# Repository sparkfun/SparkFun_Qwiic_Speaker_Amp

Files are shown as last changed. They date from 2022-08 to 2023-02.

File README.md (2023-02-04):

SparkFun Qwiic Speaker Amp
========================================

SparkFun Qwiic Speaker Amp - TPA2016D2 (https://www.sparkfun.com/products/20690)

[*SparkFun Qwiic Speaker Amp (DEV-20690)*](https://www.sparkfun.com/products/20690)

The SparkFun Qwiic Speaker Amp includes the Texas Instruments TPA2016D2 stereo, filter-free class-D audio power amplifier. What distinguishes this audio amplifier from others is that it features volume control (i.e. gain), Dynamic Range Compression (DRC), Automatic Gain Control (AGC), enable/disable amplifier, and its ability to be configured through software via I<sup>2</sup>C. Its efficient class-D operation also means low heat and long battery life when driving 4&ohm; speakers at up to 2.8W in stereo, and 8&ohm; speakers at up to 1.7W in stereo. This is quite a bit more power than the [mono amplifier (TPA2005D1) ](https://www.sparkfun.com/products/11044) or [Noisy Cricket stereo amplifier (LM4853)](https://www.sparkfun.com/products/14475). It won't shake a stadium but it will provide plenty of volume for your audio projects.

The DRC and AGC is unique compared to other audio amplifiers. This is a powerful feature that allows you to "even out" the loud and quiet sections from your audio input. It also allows you to maximize the volume of your speakers. By fine-tuning the settings, you can get the most volume to prevent distortion of the audio signal. Using the DRC, AGC, and/or the limiter alone allows you to protect your speakers from getting damaged by extremely loud playback. We've written an extensive Arduino Library that allows you to easily control all of the amplifier's features from simple gain control to advanced AGC. Note that you will need to send the configuration to the TPA2016D2 upon every power cycle. 

The board has been designed to be user friendly! Screw terminals are provided for the audio input, power, shutdown, and speaker output. A 3.5mm TRS connector is included as an alternative to easily insert an audio cable. Utilizing our handy Qwiic system, no soldering is required to connect it to the rest of your system when configuring the amplifier's settings. A power LED (PWR) is included on the board to indicate when power is applied to the amplifier through VIN. It can be disabled by cutting the LED jumper on the bottom side. For users that do not want to power the board with a separate power supply, you can close the JP1 jumper and use the same power supply as the microcontroller via the Qwiic connector's 3.3V pin.

This board is great for projects that require you to amplify an audio signal for small, differential speakers. This breakout is also great when pairing it with your smartphone, computer, portable digital player, or any audio boards (such as the MP3 Trigger, Tsunami Super WAV Trigger, MP3 Player Shield, or Music Instrument Shield to name a few)! Add the Qwiic Speaker Amp in your next portable projects such as sound effects for your spooky Halloween pumpkin, wearable costumes, props, talking greeting cards, or USB speakers.

Repository Contents
-------------------

* **/Documentation** - Datasheets, additional product information
* **/Hardware** - Eagle design files (.brd, .sch)
  * **/Production** - Production panel files (.brd)

Documentation
--------------

* **[Installing an Arduino Library Guide](https://learn.sparkfun.com/tutorials/installing-an-arduino-library)** - Basic information on how to install an Arduino library.
* **[Library](https://github.com/sparkfun/SparkFun_TPA2016D2_Arduino_Library)** - Arduino library for the Qwiic Speaker Amp.
* **[SparkFun Fritzing repo](https://github.com/sparkfun/Fritzing_Parts/blob/main/products/20690_sfe_qwiic_speaker_amplifier_tpa2016d2_stereo_audio.fzpz)** - Fritzing diagrams for SparkFun products.
* **[Hookup Guide](https://learn.sparkfun.com/tutorials/2749)** - Basic hookup guide for the Qwiic Speaker Amp.

Product Versions
----------------

* **[DEV-20690](https://www.sparkfun.com/products/20690)** - Initial release

Version History
---------------
* v1.0 - Initial release

License Information
-------------------

This product is _**open source**_! 

Please review the LICENSE.md file for license information. 

If you have any questions or concerns on licensing, please contact technical support on our [SparkFun forums](https://forum.sparkfun.com/viewforum.php?f=152).

Distributed as-is; no warranty is given.

- Your friends at SparkFun.

_<COLLABORATION CREDIT>_

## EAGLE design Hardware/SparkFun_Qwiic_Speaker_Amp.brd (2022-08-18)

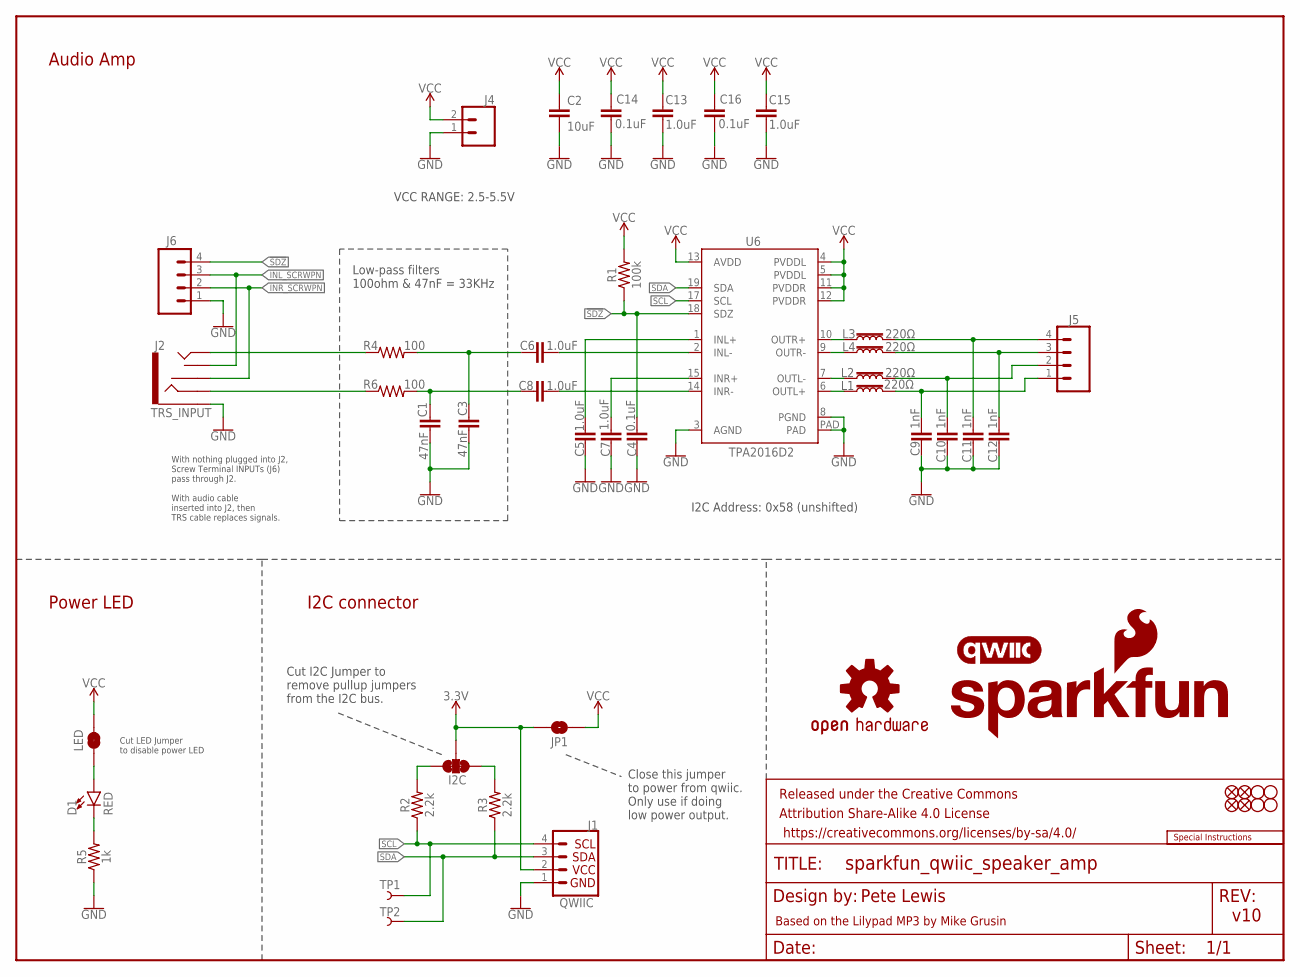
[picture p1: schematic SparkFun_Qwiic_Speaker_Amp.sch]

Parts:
C1, C3: 47nF; 0402-TIGHT
C2: 10uF; 0805
C4, C14, C16: 0.1uF; 0402-TIGHT
C5, C6, C7, C8, C13, C15: 1.0uF; 0402-TIGHT
C9, C10, C11, C12: 1nF; 0402
D1: RED; LED-0603
FD1, FD2, FD3, FD4: FIDUCIAL1X2; FIDUCIAL-1X2
FRAME2: FRAME-LETTER; CREATIVE_COMMONS
H1, H2, H3, H4: STAND-OFFTIGHT; STAND-OFF-TIGHT
I2C: JUMPER-SMT_3_2-NC_TRACE_SILK; SMT-JUMPER_3_2-NC_TRACE_SILK
J1: QWIIC; JST04_1MM_RA
J2: TRS_INPUT; AUDIO-JACK-3.5MM-SMD
J4: CONN_023.5MM; SCREWTERMINAL-3.5MM-2
J5: CONN_04SCREW; SCREWTERMINAL-3.5MM-4
J6: SCREW; SCREWTERMINAL-3.5MM-4
JP1: JP1; SMT-JUMPER_2_NO_SILK
L1, L2, L3, L4: 220Ω; 0805
LED: JUMPER-SMT_2_NC_TRACE_SILK; SMT-JUMPER_2_NC_TRACE_SILK
LOGO2: SFE_LOGO_NAME_FLAME.1_INCH; SFE_LOGO_NAME_FLAME_.1
LOGO3: QWIIC_LOGO_4MM; QWIIC_4MM
LOGO4: OSHW-LOGOS; OSHW-LOGO-S
LOGO6: SPECIAL_INSTRUCTIONS-ORDERING; ORDERING_INSTRUCTIONS
R1: 100k; 0402-TIGHT
R2, R3: 2.2k; 0402-TIGHT
R4, R6: 100; 0402-TIGHT
R5: 1k; 0402-TIGHT
TP1, TP2: TEST-POINTTP_15TH_THRU; TP_15TH
U6: TPA2016D2; QFN-20-0.5MM

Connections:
3.3V: I2C.2, J1.2, JP1.1
!SDZ!: C4.1, J6.4, R1.1, U6.18 (SDZ)
GND: C1.2, C2.2, C3.2, C4.2, C5.1, C7.1, C9.2, C10.2, C11.2, C12.2, C13.2, C14.2, C15.2, C16.2, J1.1, J2.SLEEVE, J4.1, J6.1, R5.1, U6.3 (AGND), U6.8 (PGND), U6.PAD
INL: J2.TIP, R4.1
INL_SCRWPN: J2.TSH, J6.3
INR: J2.RING, R6.1
INR_SCRWPN: J2.RSH, J6.2
unnamed: L1.1, U6.6 (OUTL+)
unnamed: L2.1, U6.7 (OUTL-)
unnamed: C1.1, C8.1, R6.2
unnamed: D1.C, R5.2
unnamed: C3.1, C6.1, R4.2
unnamed: D1.A, LED.1
unnamed: I2C.3, R2.2
unnamed: I2C.1, R3.2
unnamed: L3.1, U6.10 (OUTR+)
unnamed: L4.1, U6.9 (OUTR-)
unnamed: C8.2, U6.14 (INR-)
unnamed: C5.2, U6.1 (INL+)
unnamed: C6.2, U6.2 (INL-)
unnamed: C7.2, U6.15 (INR+)
SCL: J1.4, R2.1, TP1.1, U6.17 (SCL)
SDA: J1.3, R3.1, TP2.1, U6.19 (SDA)
SPK_L_+: C9.1, J5.1, L1.2
SPK_L_-: C10.1, J5.2, L2.2
SPK_R_+: C11.1, J5.4, L3.2
SPK_R_-: C12.1, J5.3, L4.2
VCC: C2.1, C13.1, C14.1, C15.1, C16.1, J4.2, JP1.2, LED.2, R1.2, U6.4 (PVDDL), U6.5 (PVDDL), U6.11 (PVDDR), U6.12 (PVDDR), U6.13 (AVDD)

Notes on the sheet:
Pete Lewis
Audio Amp
Cut I2C Jumper to remove pullup jumpers from the I2C bus.
v10
Based on the Lilypad MP3 by Mike Grusin
Low-pass filters 100ohm & 47nF = 33KHz
With nothing plugged into J2, Screw Terminal INPUTs (J6) pass through J2. With audio cable inserted into J2, then TRS cable replaces signals.
VCC RANGE: 2.5-5.5V
Cut LED Jumper to disable power LED
Power LED
I2C connector
Close this jumper to power from qwiic. Only use if doing low power output.
I2C Address: 0x58 (unshifted)

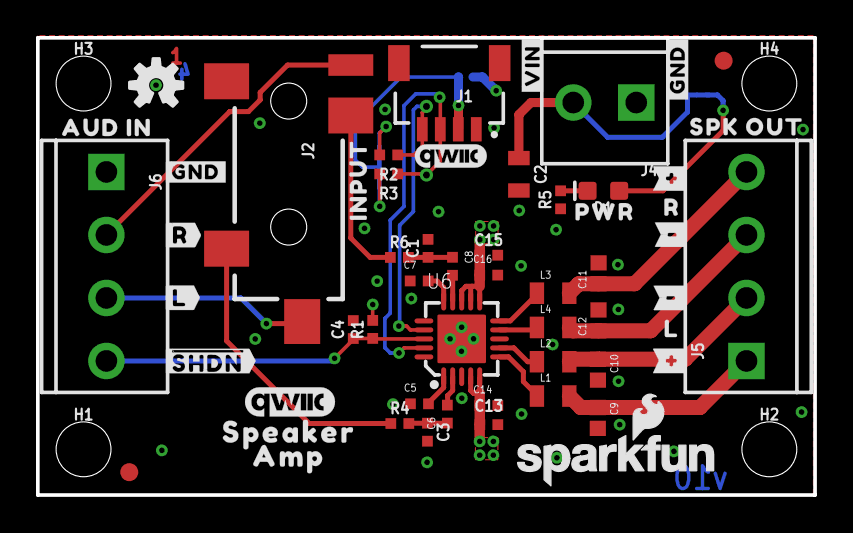
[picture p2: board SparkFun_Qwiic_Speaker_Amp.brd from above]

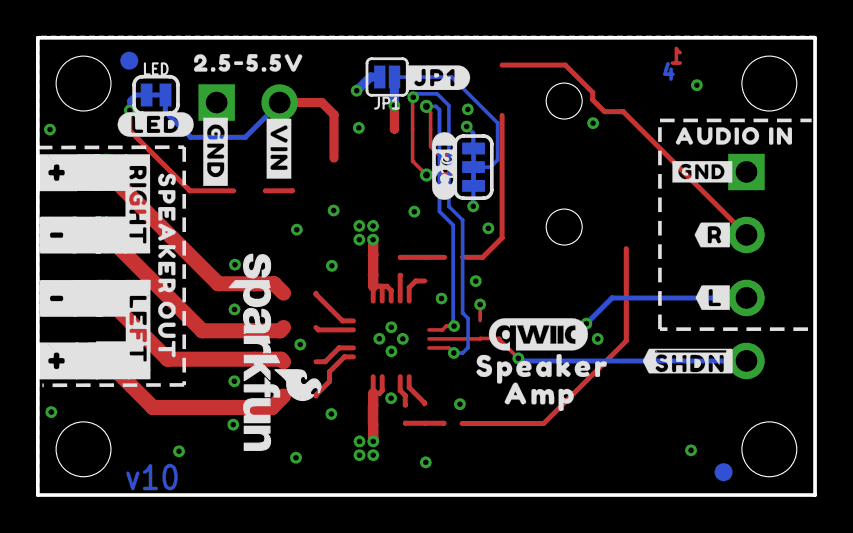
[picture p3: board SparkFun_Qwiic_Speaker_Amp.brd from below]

Board: 4 copper layers, 43.2 x 25.4 mm, 92 parts (27 on the bottom side), 28 nets.

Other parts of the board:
LOGO1: QWIIC_LOGO_4MM; QWIIC_5MM
U$1, U$4: SPEAKER0
U$2: #I2C#0
U$3: INPUT0
U$5: PWR26
U$6, U$8: AMP0
U$7: QWIIC_5.5MM
U$9, U$12: ###15
U$10, U$11: ###16
U$13: ##SHDN##3
U$14: R21
U$15: #VIN#24
U$16: L5
U$17: #R#11
U$18: #L#33
U$19: #L#12
U$20, U$25, U$29: #GND#25
U$21: SPK_OUT22
U$22: AUD_IN23
U$23: 2#5#5#5V24
U$24: #LED#27
U$26: #VIN#30
U$27: #GND#31
U$28: #R#34
U$30: SFE_LOGO_NAME_FLAME_.1
U$31, U$32: ###40
U$33: SPEAKER_OUT37
U$34: AUDIO_IN39
U$35, U$36: ###41
U$37: #LEFT#43
U$38: #RIGHT#44
U$39: #JP1#2
U$40: ##SHDN##2

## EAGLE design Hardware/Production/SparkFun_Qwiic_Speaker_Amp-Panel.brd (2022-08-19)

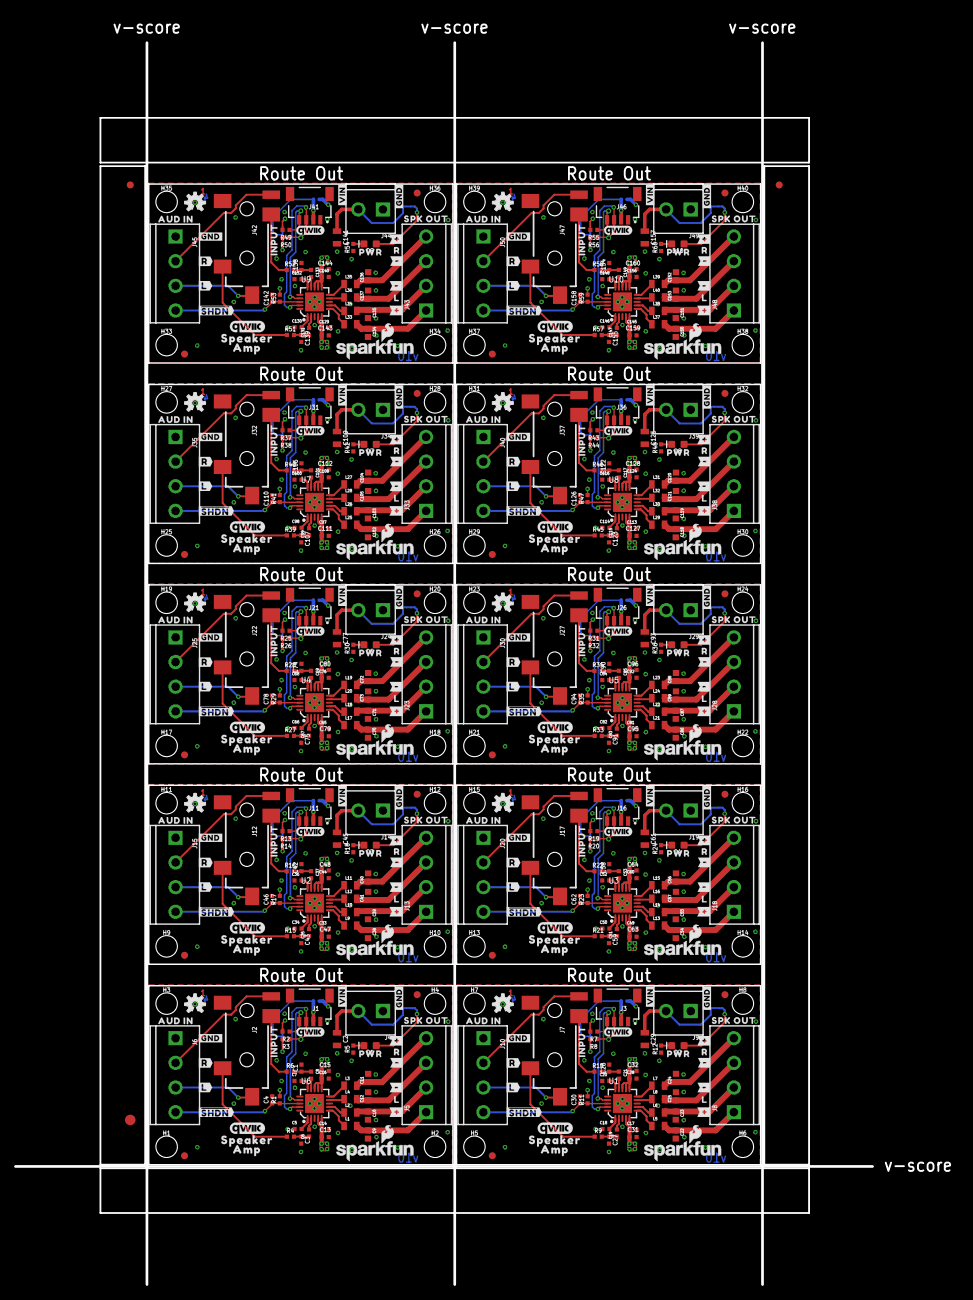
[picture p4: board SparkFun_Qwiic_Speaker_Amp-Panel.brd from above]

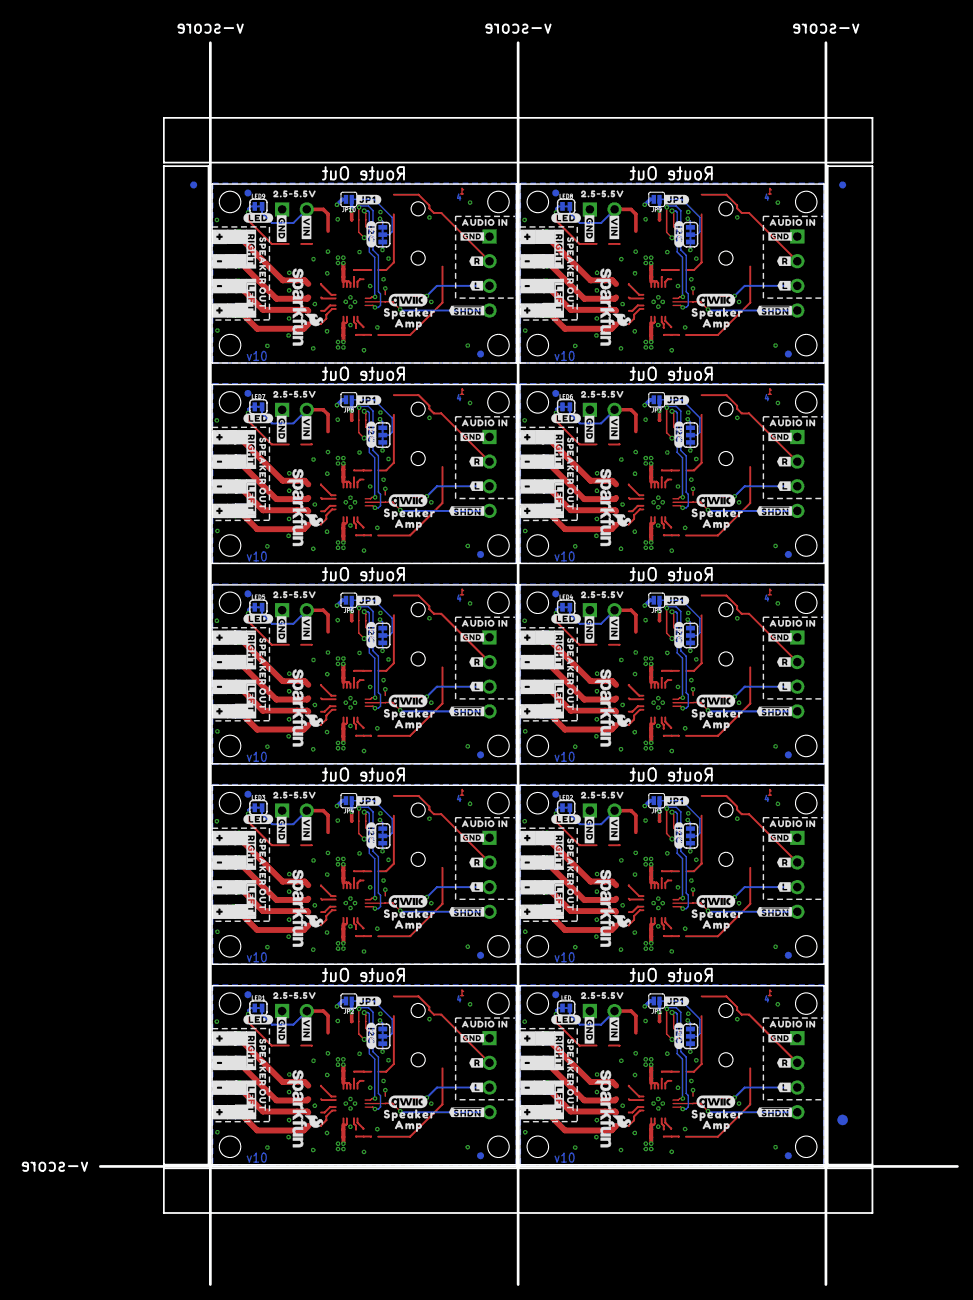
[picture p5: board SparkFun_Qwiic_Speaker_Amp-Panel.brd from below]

Board: 4 copper layers, 121.7 x 176.3 mm, 906 parts (273 on the bottom side), 280 nets.

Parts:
C1, C3, C26, C27, C42, C43, C58, C59, C74, C75, C90, C91, C106, C107, C122, C123, C138, C139, C154, C155: 47nF; 0402-TIGHT
C2, C29, C45, C61, C77, C93, C109, C125, C141, C157: 10uF; 0805
C4, C14, C16, C17, C28, C30, C33, C44, C46, C49, C60, C62, C65, C76, C78, C81, C92, C94, C97, C108, C110, C113, C124, C126, C129, C140, C142, C145, C156, C158: 0.1uF; 0402-TIGHT
C5, C6, C7, C8, C13, C15, C18, C19, C20, C21, C31, C32, C34, C35, C36, C37, C47, C48, C50, C51, C52, C53, C63, C64, C66, C67, C68, C69, C79, C80, C82, C83, C84, C85, C95, C96, C98, C99, C100, C101, C111, C112, C114, C115, C116, C117, C127, C128, C130, C131, C132, C133, C143, C144, C146, C147, C148, C149, C159, C160: 1.0uF; 0402-TIGHT
C9, C10, C11, C12, C22, C23, C24, C25, C38, C39, C40, C41, C54, C55, C56, C57, C70, C71, C72, C73, C86, C87, C88, C89, C102, C103, C104, C105, C118, C119, C120, C121, C134, C135, C136, C137, C150, C151, C152, C153: 1nF; 0402
D1, D2, D3, D4, D5, D6, D7, D8, D9, D10: RED; LED-0603
E$1, E$2, E$3, E$4: FIDUCIAL-1X2
E$5, E$6: FIDUCIAL-1.5X3
FD1, FD2, FD3, FD4, FD5, FD6, FD7, FD8, FD9, FD10, FD11, FD12, FD13, FD14, FD15, FD16, FD17, FD18, FD19, FD20, FD21, FD22, FD23, FD24, FD25, FD26, FD27, FD28, FD29, FD30, FD31, FD32, FD33, FD34, FD35, FD36, FD37, FD38, FD39, FD40: FIDUCIAL1X2; FIDUCIAL-1X2
H1, H2, H3, H4, H5, H6, H7, H8, H9, H10, H11, H12, H13, H14, H15, H16, H17, H18, H19, H20, H21, H22, H23, H24, H25, H26, H27, H28, H29, H30, H31, H32, H33, H34, H35, H36, H37, H38, H39, H40: STAND-OFFTIGHT; STAND-OFF-TIGHT
I2C, I2C1, I2C2, I2C3, I2C4, I2C5, I2C6, I2C7, I2C8, I2C9: JUMPER-SMT_3_2-NC_TRACE_SILK; SMT-JUMPER_3_2-NC_TRACE_SILK
J1, J3, J11, J16, J21, J26, J31, J36, J41, J46: QWIIC; JST04_1MM_RA
J2, J7, J12, J17, J22, J27, J32, J37, J42, J47: TRS_INPUT; AUDIO-JACK-3.5MM-SMD
J4, J9, J14, J19, J24, J29, J34, J39, J44, J49: SCREWTERMINAL-3.5MM-2
J5, J8, J13, J18, J23, J28, J33, J38, J43, J48: SCREWTERMINAL-3.5MM-4
J6, J10, J15, J20, J25, J30, J35, J40, J45, J50: SCREW; SCREWTERMINAL-3.5MM-4
JP1, JP2, JP3, JP4, JP5, JP6, JP7, JP8, JP9, JP10: JP1; SMT-JUMPER_2_NO_SILK
L1, L2, L3, L4, L5, L6, L7, L8, L9, L10, L11, L12, L13, L14, L15, L16, L17, L18, L19, L20, L21, L22, L23, L24, L25, L26, L27, L28, L29, L30, L31, L32, L33, L34, L35, L36, L37, L38, L39, L40: 220Ω; 0805
LED, LED1, LED2, LED3, LED4, LED5, LED6, LED7, LED8, LED9: SMT-JUMPER_2_NC_TRACE_SILK
LOGO1, LOGO8, LOGO12, LOGO16, LOGO20, LOGO24, LOGO28, LOGO32, LOGO36, LOGO40: QWIIC_LOGO_4MM; QWIIC_5MM
LOGO2, LOGO5, LOGO9, LOGO13, LOGO17, LOGO21, LOGO25, LOGO29, LOGO33, LOGO37: SFE_LOGO_NAME_FLAME.1_INCH; SFE_LOGO_NAME_FLAME_.1
LOGO3, LOGO6, LOGO10, LOGO14, LOGO18, LOGO22, LOGO26, LOGO30, LOGO34, LOGO38: QWIIC_LOGO_4MM; QWIIC_4MM
LOGO4, LOGO7, LOGO11, LOGO15, LOGO19, LOGO23, LOGO27, LOGO31, LOGO35, LOGO39: OSHW-LOGOS; OSHW-LOGO-S
R1, R11, R17, R23, R29, R35, R41, R47, R53, R59: 100k; 0402-TIGHT
R2, R3, R7, R8, R13, R14, R19, R20, R25, R26, R31, R32, R37, R38, R43, R44, R49, R50, R55, R56: 2.2k; 0402-TIGHT
R4, R6, R9, R10, R15, R16, R21, R22, R27, R28, R33, R34, R39, R40, R45, R46, R51, R52, R57, R58: 100; 0402-TIGHT
R5, R12, R18, R24, R30, R36, R42, R48, R54, R60: 1k; 0402-TIGHT
TP1, TP2, TP3, TP4, TP5, TP6, TP7, TP8, TP9, TP10, TP11, TP12, TP13, TP14, TP15, TP16, TP17, TP18, TP19, TP20: TP_15TH
U1, U2, U3, U4, U5, U6, U7, U8, U9, U10: TPA2016D2; QFN-20-0.5MM
U$1, U$4, U$42, U$45, U$82, U$85, U$122, U$125, U$162, U$165, U$202, U$205, U$242, U$245, U$282, U$285, U$322, U$325, U$362, U$365: SPEAKER0
U$2, U$44, U$84, U$124, U$164, U$204, U$244, U$284, U$324, U$364: #I2C#0
U$3, U$43, U$83, U$123, U$163, U$203, U$243, U$283, U$323, U$363: INPUT0
U$5, U$61, U$101, U$141, U$181, U$221, U$261, U$301, U$341, U$381: PWR26
U$6, U$8, U$41, U$47, U$81, U$87, U$121, U$127, U$161, U$167, U$201, U$207, U$241, U$247, U$281, U$287, U$321, U$327, U$361, U$367: AMP0
U$7, U$46, U$86, U$126, U$166, U$206, U$246, U$286, U$326, U$366: QWIIC_5.5MM
U$9, U$12, U$51, U$54, U$91, U$94, U$131, U$134, U$171, U$174, U$211, U$214, U$251, U$254, U$291, U$294, U$331, U$334, U$371, U$374: ###15
U$10, U$11, U$52, U$53, U$92, U$93, U$132, U$133, U$172, U$173, U$212, U$213, U$252, U$253, U$292, U$293, U$332, U$333, U$372, U$373: ###16
U$13, U$79, U$119, U$159, U$199, U$239, U$279, U$319, U$359, U$399: ##SHDN##3
U$14, U$55, U$95, U$135, U$175, U$215, U$255, U$295, U$335, U$375: R21
U$15, U$59, U$99, U$139, U$179, U$219, U$259, U$299, U$339, U$379: #VIN#24
U$16, U$48, U$88, U$128, U$168, U$208, U$248, U$288, U$328, U$368: L5
U$17, U$49, U$89, U$129, U$169, U$209, U$249, U$289, U$329, U$369: #R#11
U$18, U$66, U$106, U$146, U$186, U$226, U$266, U$306, U$346, U$386: #L#33
U$19, U$50, U$90, U$130, U$170, U$210, U$250, U$290, U$330, U$370: #L#12
U$20, U$25, U$29, U$60, U$63, U$68, U$100, U$103, U$108, U$140, U$143, U$148, U$180, U$183, U$188, U$220, U$223, U$228, U$260, U$263, U$268, U$300, U$303, U$308, U$340, U$343, U$348, U$380, U$383, U$388: #GND#25
U$21, U$56, U$96, U$136, U$176, U$216, U$256, U$296, U$336, U$376: SPK_OUT22
U$22, U$57, U$97, U$137, U$177, U$217, U$257, U$297, U$337, U$377: AUD_IN23
U$23, U$58, U$98, U$138, U$178, U$218, U$258, U$298, U$338, U$378: 2#5#5#5V24
U$24, U$62, U$102, U$142, U$182, U$222, U$262, U$302, U$342, U$382: #LED#27
U$26, U$64, U$104, U$144, U$184, U$224, U$264, U$304, U$344, U$384: #VIN#30
U$27, U$65, U$105, U$145, U$185, U$225, U$265, U$305, U$345, U$385: #GND#31
U$28, U$67, U$107, U$147, U$187, U$227, U$267, U$307, U$347, U$387: #R#34
U$30, U$80, U$120, U$160, U$200, U$240, U$280, U$320, U$360, U$400: SFE_LOGO_NAME_FLAME_.1
U$31, U$32, U$71, U$72, U$111, U$112, U$151, U$152, U$191, U$192, U$231, U$232, U$271, U$272, U$311, U$312, U$351, U$352, U$391, U$392: ###40
U$33, U$69, U$109, U$149, U$189, U$229, U$269, U$309, U$349, U$389: SPEAKER_OUT37
U$34, U$70, U$110, U$150, U$190, U$230, U$270, U$310, U$350, U$390: AUDIO_IN39
U$35, U$36, U$73, U$74, U$113, U$114, U$153, U$154, U$193, U$194, U$233, U$234, U$273, U$274, U$313, U$314, U$353, U$354, U$393, U$394: ###41
U$37, U$75, U$115, U$155, U$195, U$235, U$275, U$315, U$355, U$395: #LEFT#43
U$38, U$76, U$116, U$156, U$196, U$236, U$276, U$316, U$356, U$396: #RIGHT#44
U$39, U$77, U$117, U$157, U$197, U$237, U$277, U$317, U$357, U$397: #JP1#2
U$40, U$78, U$118, U$158, U$198, U$238, U$278, U$318, U$358, U$398: ##SHDN##2

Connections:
3.3V: I2C.2, J1.2, JP1.1
3.3V1: I2C1.2, J3.2, JP2.1
3.3V2: I2C2.2, J11.2, JP3.1
3.3V3: I2C3.2, J16.2, JP4.1
3.3V4: I2C4.2, J21.2, JP5.1
3.3V5: I2C5.2, J26.2, JP6.1
3.3V6: I2C6.2, J31.2, JP7.1
3.3V7: I2C7.2, J36.2, JP8.1
3.3V8: I2C8.2, J41.2, JP9.1
3.3V9: I2C9.2, J46.2, JP10.1
!SDZ!: C4.1, J6.4, R1.1, U6.18
!SDZ!1: C30.1, J10.4, R11.1, U1.18
!SDZ!2: C46.1, J15.4, R17.1, U2.18
!SDZ!3: C62.1, J20.4, R23.1, U3.18
!SDZ!4: C78.1, J25.4, R29.1, U4.18
!SDZ!5: C94.1, J30.4, R35.1, U5.18
!SDZ!6: C110.1, J35.4, R41.1, U7.18
!SDZ!7: C126.1, J40.4, R47.1, U8.18
!SDZ!8: C142.1, J45.4, R53.1, U9.18
!SDZ!9: C158.1, J50.4, R59.1, U10.18
GND: C1.2, C2.2, C3.2, C4.2, C5.1, C7.1, C9.2, C10.2, C11.2, C12.2, C13.2, C14.2, C15.2, C16.2, J1.1, J2.SLEEVE, J4.1, J6.1, R5.1, U6.3, U6.8, U6.PAD
GND1: C17.2, C18.1, C20.1, C22.2, C23.2, C24.2, C25.2, C26.2, C27.2, C28.2, C29.2, C30.2, C31.2, C32.2, J3.1, J7.SLEEVE, J9.1, J10.1, R12.1, U1.3, U1.8, U1.PAD
GND2: C33.2, C34.1, C36.1, C38.2, C39.2, C40.2, C41.2, C42.2, C43.2, C44.2, C45.2, C46.2, C47.2, C48.2, J11.1, J12.SLEEVE, J14.1, J15.1, R18.1, U2.3, U2.8, U2.PAD
GND3: C49.2, C50.1, C52.1, C54.2, C55.2, C56.2, C57.2, C58.2, C59.2, C60.2, C61.2, C62.2, C63.2, C64.2, J16.1, J17.SLEEVE, J19.1, J20.1, R24.1, U3.3, U3.8, U3.PAD
GND4: C65.2, C66.1, C68.1, C70.2, C71.2, C72.2, C73.2, C74.2, C75.2, C76.2, C77.2, C78.2, C79.2, C80.2, J21.1, J22.SLEEVE, J24.1, J25.1, R30.1, U4.3, U4.8, U4.PAD
GND5: C81.2, C82.1, C84.1, C86.2, C87.2, C88.2, C89.2, C90.2, C91.2, C92.2, C93.2, C94.2, C95.2, C96.2, J26.1, J27.SLEEVE, J29.1, J30.1, R36.1, U5.3, U5.8, U5.PAD
GND6: C97.2, C98.1, C100.1, C102.2, C103.2, C104.2, C105.2, C106.2, C107.2, C108.2, C109.2, C110.2, C111.2, C112.2, J31.1, J32.SLEEVE, J34.1, J35.1, R42.1, U7.3, U7.8, U7.PAD
GND7: C113.2, C114.1, C116.1, C118.2, C119.2, C120.2, C121.2, C122.2, C123.2, C124.2, C125.2, C126.2, C127.2, C128.2, J36.1, J37.SLEEVE, J39.1, J40.1, R48.1, U8.3, U8.8, U8.PAD
GND8: C129.2, C130.1, C132.1, C134.2, C135.2, C136.2, C137.2, C138.2, C139.2, C140.2, C141.2, C142.2, C143.2, C144.2, J41.1, J42.SLEEVE, J44.1, J45.1, R54.1, U9.3, U9.8, U9.PAD
GND9: C145.2, C146.1, C148.1, C150.2, C151.2, C152.2, C153.2, C154.2, C155.2, C156.2, C157.2, C158.2, C159.2, C160.2, J46.1, J47.SLEEVE, J49.1, J50.1, R60.1, U10.3, U10.8, U10.PAD
INL: J2.TIP, R4.1
INL1: J7.TIP, R9.1
INL2: J12.TIP, R15.1
INL3: J17.TIP, R21.1
INL4: J22.TIP, R27.1
INL5: J27.TIP, R33.1
INL6: J32.TIP, R39.1
INL7: J37.TIP, R45.1
INL8: J42.TIP, R51.1
INL9: J47.TIP, R57.1
INL_SCRWPN: J2.TSH, J6.3
INL_SCRWPN1: J7.TSH, J10.3
INL_SCRWPN2: J12.TSH, J15.3
INL_SCRWPN3: J17.TSH, J20.3
INL_SCRWPN4: J22.TSH, J25.3
INL_SCRWPN5: J27.TSH, J30.3
INL_SCRWPN6: J32.TSH, J35.3
INL_SCRWPN7: J37.TSH, J40.3
INL_SCRWPN8: J42.TSH, J45.3
INL_SCRWPN9: J47.TSH, J50.3
INR: J2.RING, R6.1
INR1: J7.RING, R10.1
INR2: J12.RING, R16.1
INR3: J17.RING, R22.1
INR4: J22.RING, R28.1
INR5: J27.RING, R34.1
INR6: J32.RING, R40.1
INR7: J37.RING, R46.1
INR8: J42.RING, R52.1
INR9: J47.RING, R58.1
INR_SCRWPN: J2.RSH, J6.2
INR_SCRWPN1: J7.RSH, J10.2
INR_SCRWPN2: J12.RSH, J15.2
INR_SCRWPN3: J17.RSH, J20.2
INR_SCRWPN4: J22.RSH, J25.2
INR_SCRWPN5: J27.RSH, J30.2
INR_SCRWPN6: J32.RSH, J35.2
INR_SCRWPN7: J37.RSH, J40.2
INR_SCRWPN8: J42.RSH, J45.2
INR_SCRWPN9: J47.RSH, J50.2
unnamed: L1.1, U6.6
unnamed: L2.1, U6.7
unnamed: C1.1, C8.1, R6.2
unnamed: D1.C, R5.2
unnamed: C3.1, C6.1, R4.2
unnamed: D1.A, LED.1
unnamed: I2C1.3, R7.2
unnamed: I2C1.1, R8.2
unnamed: C18.2, U1.1
unnamed: C21.2, U1.14
unnamed: C20.2, U1.15
unnamed: C19.2, U1.2
unnamed: L5.1, U1.6
unnamed: L6.1, U1.7
unnamed: L7.1, U1.10
unnamed: I2C.3, R2.2
unnamed: I2C.1, R3.2
unnamed: L3.1, U6.10
unnamed: L4.1, U6.9
unnamed: C8.2, U6.14
unnamed: C5.2, U6.1
unnamed: C6.2, U6.2
unnamed: L8.1, U1.9
unnamed: C21.1, C26.1, R10.2
unnamed: C7.2, U6.15
unnamed: C19.1, C27.1, R9.2
unnamed: D2.C, R12.2
unnamed: D2.A, LED1.1
unnamed: I2C2.3, R13.2
unnamed: I2C2.1, R14.2
unnamed: C34.2, U2.1
unnamed: C37.2, U2.14
unnamed: C36.2, U2.15
unnamed: C35.2, U2.2
unnamed: L9.1, U2.6
unnamed: L10.1, U2.7
unnamed: L11.1, U2.10
unnamed: L12.1, U2.9
unnamed: C37.1, C42.1, R16.2
unnamed: C35.1, C43.1, R15.2
unnamed: D3.C, R18.2
unnamed: D3.A, LED2.1
unnamed: I2C3.3, R19.2
unnamed: I2C3.1, R20.2
unnamed: C50.2, U3.1
unnamed: C53.2, U3.14
unnamed: C52.2, U3.15
unnamed: C51.2, U3.2
unnamed: L13.1, U3.6
unnamed: L14.1, U3.7
unnamed: L15.1, U3.10
unnamed: L16.1, U3.9
unnamed: C53.1, C58.1, R22.2
unnamed: C51.1, C59.1, R21.2
unnamed: D4.C, R24.2
unnamed: D4.A, LED3.1
unnamed: I2C4.3, R25.2
unnamed: I2C4.1, R26.2
unnamed: C66.2, U4.1
unnamed: C69.2, U4.14
unnamed: C68.2, U4.15
unnamed: C67.2, U4.2
unnamed: L17.1, U4.6
unnamed: L18.1, U4.7
unnamed: L19.1, U4.10
unnamed: L20.1, U4.9
unnamed: C69.1, C74.1, R28.2
unnamed: C67.1, C75.1, R27.2
unnamed: D5.C, R30.2
unnamed: D5.A, LED4.1
unnamed: I2C5.3, R31.2
unnamed: I2C5.1, R32.2
unnamed: C82.2, U5.1
unnamed: C85.2, U5.14
unnamed: C84.2, U5.15
unnamed: C83.2, U5.2
unnamed: L21.1, U5.6
unnamed: L22.1, U5.7
unnamed: L23.1, U5.10
unnamed: L24.1, U5.9
unnamed: C85.1, C90.1, R34.2
unnamed: C83.1, C91.1, R33.2
unnamed: D6.C, R36.2
unnamed: D6.A, LED5.1
unnamed: I2C6.3, R37.2
unnamed: I2C6.1, R38.2
unnamed: C98.2, U7.1
unnamed: C101.2, U7.14
unnamed: C100.2, U7.15
unnamed: C99.2, U7.2
unnamed: L25.1, U7.6
unnamed: L26.1, U7.7
unnamed: L27.1, U7.10
unnamed: L28.1, U7.9
unnamed: C101.1, C106.1, R40.2
unnamed: C99.1, C107.1, R39.2
unnamed: D7.C, R42.2
unnamed: D7.A, LED6.1
unnamed: I2C7.3, R43.2
unnamed: I2C7.1, R44.2
unnamed: C114.2, U8.1
unnamed: C117.2, U8.14
unnamed: C116.2, U8.15
unnamed: C115.2, U8.2
unnamed: L29.1, U8.6
unnamed: L30.1, U8.7
unnamed: L31.1, U8.10
unnamed: L32.1, U8.9
unnamed: C117.1, C122.1, R46.2
unnamed: C115.1, C123.1, R45.2
unnamed: D8.C, R48.2
unnamed: D8.A, LED7.1
unnamed: I2C8.3, R49.2
unnamed: I2C8.1, R50.2
unnamed: C130.2, U9.1
unnamed: C133.2, U9.14
unnamed: C132.2, U9.15
unnamed: C131.2, U9.2
unnamed: L33.1, U9.6
unnamed: L34.1, U9.7
unnamed: L35.1, U9.10
unnamed: L36.1, U9.9
unnamed: C133.1, C138.1, R52.2
unnamed: C131.1, C139.1, R51.2
unnamed: D9.C, R54.2
unnamed: D9.A, LED8.1
unnamed: I2C9.3, R55.2
unnamed: I2C9.1, R56.2
unnamed: C146.2, U10.1
unnamed: C149.2, U10.14
unnamed: C148.2, U10.15
unnamed: C147.2, U10.2
unnamed: L37.1, U10.6
unnamed: L38.1, U10.7
unnamed: L39.1, U10.10
unnamed: L40.1, U10.9
unnamed: C149.1, C154.1, R58.2
unnamed: C147.1, C155.1, R57.2
unnamed: D10.C, R60.2
unnamed: D10.A, LED9.1
SCL: J1.4, R2.1, TP1.1, U6.17
SCL1: J3.4, R7.1, TP3.1, U1.17
SCL2: J11.4, R13.1, TP5.1, U2.17
SCL3: J16.4, R19.1, TP7.1, U3.17
SCL4: J21.4, R25.1, TP9.1, U4.17
SCL5: J26.4, R31.1, TP11.1, U5.17
SCL6: J31.4, R37.1, TP13.1, U7.17
SCL7: J36.4, R43.1, TP15.1, U8.17
SCL8: J41.4, R49.1, TP17.1, U9.17
SCL9: J46.4, R55.1, TP19.1, U10.17
SDA: J1.3, R3.1, TP2.1, U6.19
SDA1: J3.3, R8.1, TP4.1, U1.19
SDA2: J11.3, R14.1, TP6.1, U2.19
SDA3: J16.3, R20.1, TP8.1, U3.19
SDA4: J21.3, R26.1, TP10.1, U4.19
SDA5: J26.3, R32.1, TP12.1, U5.19
SDA6: J31.3, R38.1, TP14.1, U7.19
SDA7: J36.3, R44.1, TP16.1, U8.19
SDA8: J41.3, R50.1, TP18.1, U9.19
SDA9: J46.3, R56.1, TP20.1, U10.19
SPK_L_+: C9.1, J5.1, L1.2
SPK_L_+1: C22.1, J8.1, L5.2
SPK_L_+2: C38.1, J13.1, L9.2
SPK_L_+3: C54.1, J18.1, L13.2
SPK_L_+4: C70.1, J23.1, L17.2
SPK_L_+5: C86.1, J28.1, L21.2
SPK_L_+6: C102.1, J33.1, L25.2
SPK_L_+7: C118.1, J38.1, L29.2
SPK_L_+8: C134.1, J43.1, L33.2
SPK_L_+9: C150.1, J48.1, L37.2
SPK_L_-: C10.1, J5.2, L2.2
SPK_L_-1: C23.1, J8.2, L6.2
SPK_L_-2: C39.1, J13.2, L10.2
SPK_L_-3: C55.1, J18.2, L14.2
SPK_L_-4: C71.1, J23.2, L18.2
SPK_L_-5: C87.1, J28.2, L22.2
SPK_L_-6: C103.1, J33.2, L26.2
SPK_L_-7: C119.1, J38.2, L30.2
SPK_L_-8: C135.1, J43.2, L34.2
SPK_L_-9: C151.1, J48.2, L38.2
SPK_R_+: C11.1, J5.4, L3.2
SPK_R_+1: C24.1, J8.4, L7.2
SPK_R_+2: C40.1, J13.4, L11.2
SPK_R_+3: C56.1, J18.4, L15.2
SPK_R_+4: C72.1, J23.4, L19.2
SPK_R_+5: C88.1, J28.4, L23.2
SPK_R_+6: C104.1, J33.4, L27.2
SPK_R_+7: C120.1, J38.4, L31.2
SPK_R_+8: C136.1, J43.4, L35.2
SPK_R_+9: C152.1, J48.4, L39.2
SPK_R_-: C12.1, J5.3, L4.2
SPK_R_-1: C25.1, J8.3, L8.2
SPK_R_-2: C41.1, J13.3, L12.2
SPK_R_-3: C57.1, J18.3, L16.2
SPK_R_-4: C73.1, J23.3, L20.2
SPK_R_-5: C89.1, J28.3, L24.2
SPK_R_-6: C105.1, J33.3, L28.2
SPK_R_-7: C121.1, J38.3, L32.2
SPK_R_-8: C137.1, J43.3, L36.2
SPK_R_-9: C153.1, J48.3, L40.2
VCC: C2.1, C13.1, C14.1, C15.1, C16.1, J4.2, JP1.2, LED.2, R1.2, U6.4, U6.5, U6.11, U6.12, U6.13
VCC1: C17.1, C28.1, C29.1, C31.1, C32.1, J9.2, JP2.2, LED1.2, R11.2, U1.4, U1.5, U1.11, U1.12, U1.13
VCC2: C33.1, C44.1, C45.1, C47.1, C48.1, J14.2, JP3.2, LED2.2, R17.2, U2.4, U2.5, U2.11, U2.12, U2.13
VCC3: C49.1, C60.1, C61.1, C63.1, C64.1, J19.2, JP4.2, LED3.2, R23.2, U3.4, U3.5, U3.11, U3.12, U3.13
VCC4: C65.1, C76.1, C77.1, C79.1, C80.1, J24.2, JP5.2, LED4.2, R29.2, U4.4, U4.5, U4.11, U4.12, U4.13
VCC5: C81.1, C92.1, C93.1, C95.1, C96.1, J29.2, JP6.2, LED5.2, R35.2, U5.4, U5.5, U5.11, U5.12, U5.13
VCC6: C97.1, C108.1, C109.1, C111.1, C112.1, J34.2, JP7.2, LED6.2, R41.2, U7.4, U7.5, U7.11, U7.12, U7.13
VCC7: C113.1, C124.1, C125.1, C127.1, C128.1, J39.2, JP8.2, LED7.2, R47.2, U8.4, U8.5, U8.11, U8.12, U8.13
VCC8: C129.1, C140.1, C141.1, C143.1, C144.1, J44.2, JP9.2, LED8.2, R53.2, U9.4, U9.5, U9.11, U9.12, U9.13
VCC9: C145.1, C156.1, C157.1, C159.1, C160.1, J49.2, JP10.2, LED9.2, R59.2, U10.4, U10.5, U10.11, U10.12, U10.13

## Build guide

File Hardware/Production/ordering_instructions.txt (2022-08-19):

panel size, 101x158mm
PCB thickness, 1.6mm
number of layers, 4
soldermask color, Red
silkscreen color, White
oz copper, 1oz
finish, HASL lead free
stencils, top
pcs per panel, 10
min trace width, 0.2032mm / 0.0080in
min drill size, 0.3048mm / 0.0120in
filename to layer stackup 1/2/3/4: GTL, GL2, GL3, GBL

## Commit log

2022-08-10 Initial layout getting close
    [SparkFun_Qwiic_Audio_Amp.brd, SparkFun_Qwiic_Audio_Amp.sch]
2022-08-11 Layout done v01
    [SparkFun_Qwiic_Audio_Amp.brd, SparkFun_Qwiic_Audio_Amp.sch]
2022-08-11 swapped inner layers to correct (2=GND, 15=VCC)
    [SparkFun_Qwiic_Audio_Amp.brd, SparkFun_Qwiic_Audio_Amp.sch]
2022-08-12 schematic cleanup and minor board fixes
    -more gnd vias
    -drc approvals
    [SparkFun_Qwiic_Audio_Amp.brd, SparkFun_Qwiic_Audio_Amp.sch]
2022-08-12 correcting file names to match product name
    [SparkFun_Qwiic_Speaker_Amp.brd, SparkFun_Qwiic_Speaker_Amp.sch]
2022-08-12 Full SparkFun and flame logo on top silk
    [SparkFun_Qwiic_Speaker_Amp.brd, SparkFun_Qwiic_Speaker_Amp.sch]
2022-08-12 moved 1/2/3/4 copper to avoid drc errors
    -adjusted trace of SCL near IC to avoid acid trap
    -rotated vias under IC to avoid being directly under where paste openings are.
    [SparkFun_Qwiic_Speaker_Amp.brd]
2022-08-17 Added more VCC vias for connection to IC power pins.
    -also thickened up the VCC traces to IC.
    -bumped version to V10 in sch and brd
    [SparkFun_Qwiic_Speaker_Amp.brd, SparkFun_Qwiic_Speaker_Amp.sch]
2022-08-18 increased qwiic logo size
    -fixed one wire stub
    [SparkFun_Qwiic_Speaker_Amp.brd]
2022-08-19 production panel v10
    [SparkFun_Qwiic_Speaker_Amp-Panel.brd]

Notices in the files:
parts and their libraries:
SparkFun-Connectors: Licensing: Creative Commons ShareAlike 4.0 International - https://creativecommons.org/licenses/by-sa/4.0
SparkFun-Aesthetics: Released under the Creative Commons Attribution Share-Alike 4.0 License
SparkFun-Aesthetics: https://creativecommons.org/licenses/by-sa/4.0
